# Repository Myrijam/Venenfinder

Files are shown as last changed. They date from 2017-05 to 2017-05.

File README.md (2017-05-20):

# Venenfinder
Assistive medical device to help localizing veins for intravenous access...

Medication that can’t be ingested through the gastrointestinal tract has to be injected intravenous - usually by a doctor but in chronic diseases it can also be carried out by yourself  ("home treatment", for example, venous puncture with medication 3 times per week).
Venous blood vessels used for medication are not always easy to recognize and if the needle is not secure in the vein, it must be punctured again at another point.  Here our project comes into play: Using NIR (near infrared) Illumination and real-time image processing, we can make the veins more visible!

We (my brother Elias, Lucie [a friend of mine] and me) submitted this project to Jugend Forscht. It will take part in the German Final in a week! Please keep your fingers crossed...
Our aim was to develop an assistive technology for venous puncture for diagnostic purposes (blood sampling) or for medical drug administration.
Easy reproduction and low costs are important criteria for development.

In addition to the research and review of specialist literature on methods of venous localization and optical characteristics of human skin, we carry out our own experiments. This Project contains the Python code needed for a mobile version that uses a smartphone or tablet as a display as well as the 3d-files needed to print it.
Please check the setup-file for a detailed description.

This Project is licensed under the Creative Commens license: CC BY NC SA.

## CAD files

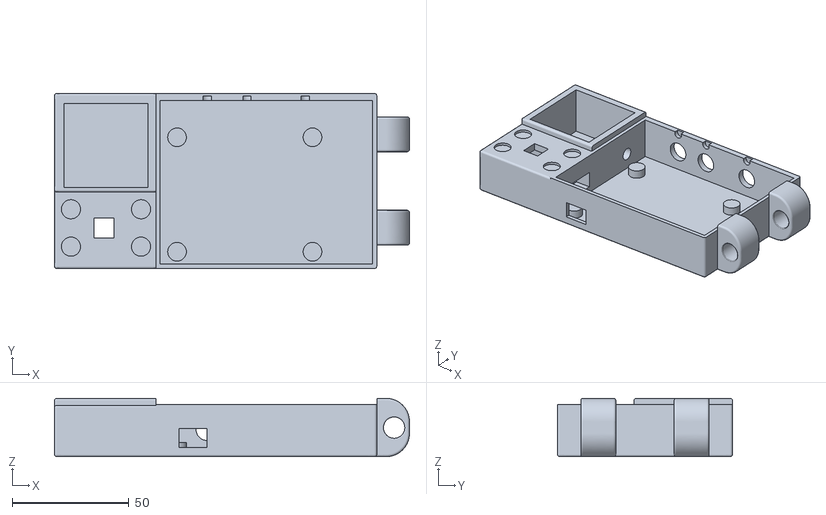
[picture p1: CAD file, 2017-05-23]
3d_files/Vene_main_case.stl
152.0 x 75.0 x 25.0

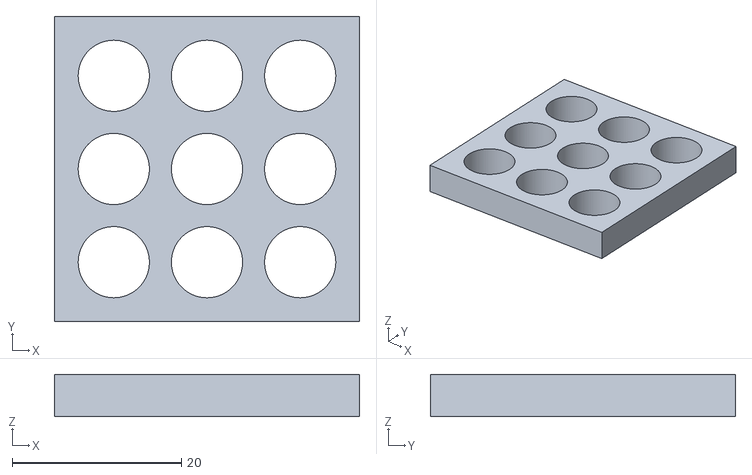
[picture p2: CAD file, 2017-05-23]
3d_files/IR-LED-reflector-Matrix_Venenfinder.stl
36.0 x 36.0 x 5.00

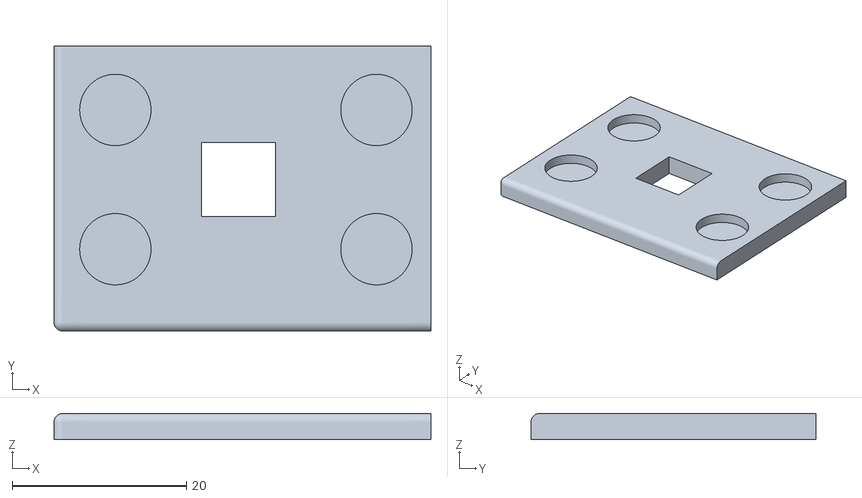
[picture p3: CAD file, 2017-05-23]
3d_files/IR-Filter_MagneticClip_Venenfinder.stl
43.3 x 32.8 x 3.00

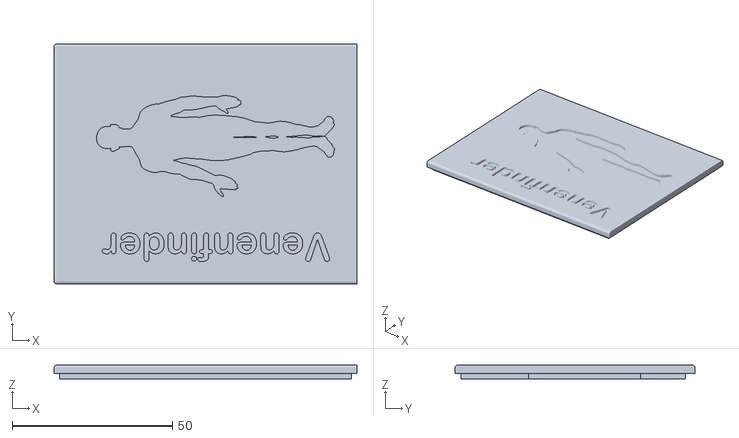
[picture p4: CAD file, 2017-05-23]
3d_files/Cover_Venenfinder.stl
94.5 x 75.0 x 4.40

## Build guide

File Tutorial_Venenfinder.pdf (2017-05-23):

Venenfinder – a DIY medical assistive device.
Elias Stoetzer (12), Lucie Ettlinger (16), Myrijam Stoetzer (16)

Venenfinder – a DIY medical assistive device.

This tutorial describes how to build the „Venenfinder“ (vein-finder) from scratch. It is a medical assistive device that was developed by us to make it easier for medical stuff as well as people with chronic illnesses to get vein access.

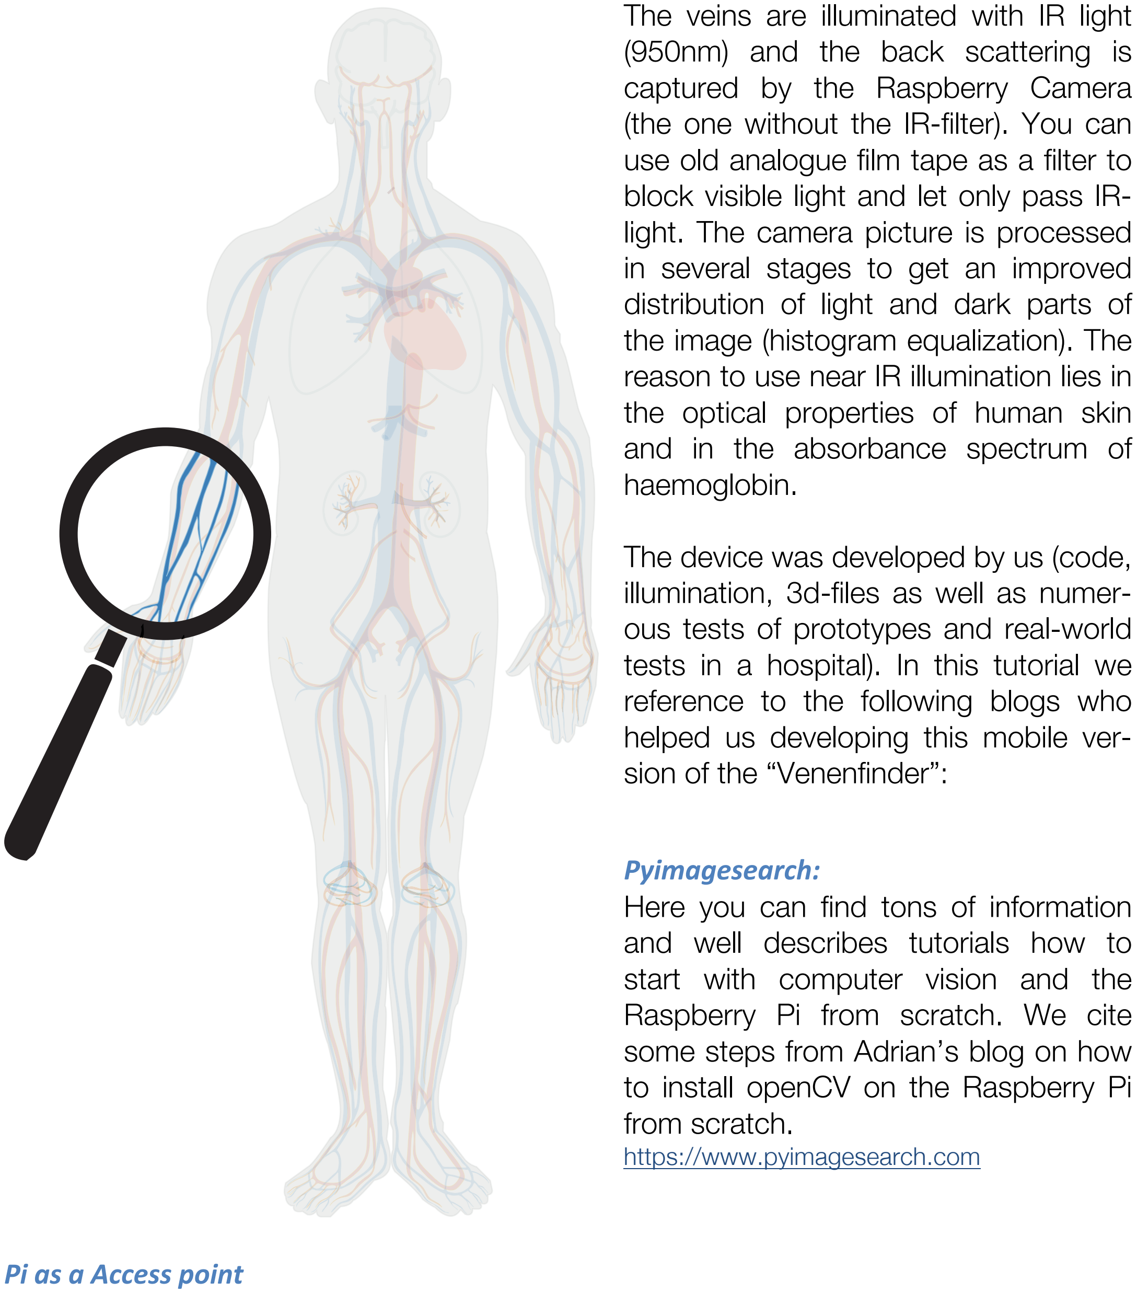
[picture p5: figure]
The veins are illuminated with IR light (950nm) and the back scattering is captured by the Raspberry Camera; light. The camera picture is processed in several stages to get an improved distribution of light and dark parts of the image (histogram equalization). The; the optical properties of human skin and in the absorbance spectrum of haemoglobin.; The device was developed by us (code,; ous tests of prototypes and real-world; reference to the following blogs who helped us developing this mobile ver- sion of the “Venenfinder”: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

(the one without the IR-filter). You can use old analogue film tape as a filter to block visible light and let only pass IR-

reason to use near IR illumination lies in

illumination, 3d-files as well as numer-

tests in a hospital). In this tutorial we

If you want to stream the calculated image to your smartphone, TV or tablet, you either need to integrate the Raspberry into your local Wifi network – or just start a new one. We don’t want the user to have to deal with editing wifi settings on a terminal session, so we just decided to turn the Pi into a Hotspot. Here we followed Phil Martin’s blog on how to use the Raspberry as a Wifi Accesspoint:
https://frillip.com/using-your-raspberry-pi-3-as-a-wifi-access-point-with-hostapd/

Rotary encoder:
Since you need a way to change the setting of the image enhancement, we decided to use rotary encoders. These are basically just 2 switches and they sequence they close and open tells you the direction the knob was turned.
We soldered 3 rotary encoders to a little board and created a Raspberry HAT on our own. For the code we used:
http://www.bobrathbone.com/raspberrypi/Raspberry%20Rotary%20Encoders.pdf

Streaming Server in Python:
We used some code from Igor Maculan – he programmed a Simple Python Motion Jpeg (mjpeg) Server using a webcam, and we changed it to Picam, added the encoder and display of parameters. Original Code:
https://gist.github.com/n3wtron/4624820

## Install / Compile Softwarecomponents

1. download Jessie (full) from Raspberri.org (Version 2017-04-10)
2. unzip file and write the image to an SD-Card (e.g. using Apple Pi-Baker or other tools; see e.g. https://www.raspberrypi.org/documentation/installation/installingimages/)
3. start the system with the new sd-card and configure it according to... http://www.pyimagesearch.com/2016/04/18/install-guide-raspberry-pi-3-raspbian-jessie-opencv-3/
4. Make sure network connections work (WiFi or LAN) – you need to download software packets

Steps to install the Software, OS, Network

Follow the steps in Adrian’s tutorial http://www.pyimagesearch.com/2015/10/26/howto-install-opencv-3-on-raspbian-jessie/

1. expand filesystem (automatic)
2. updates: (sudo apt-get update & sudo apt-get upgrade)
3. install the packages as described, but download opencv3.2 and additions for 3.2

Install packages:
developer tools:
sudo apt-get install build-essential git cmake pkg-config
image I/O packages
sudo apt-get install libjpeg-dev libtiff5-dev libjasper-dev libpng12-dev

video I/O packages:
sudo apt-get install libavcodec-dev libavformat-dev libswscale-dev libv4ldev
sudo apt-get install libxvidcore-dev libx264-dev
display images, gui etc:
sudo apt-get install libgtk2.0-dev
extra optimation for matrix operations:
sudo apt-get install libatlas-base-dev gfortran
Python 2.7 und 3 header files:
sudo apt-get install python2.7-dev python3-dev
Source-Files:
wget -O opencv.zip https://github.com/Itseez/opencv/archive/3.2.0.zip unzip opencv.zip

wget -O opencv_contrib.zip https://github.com/Itseez/opencv_contrib/archive/3.2.0.zip
unzip opencv_contrib.zip
python package manager
wget https://bootstrap.pypa.io/get-pip.py sudo python get-pip.py
install numpy (numerical python)
pip install numpy
compile opencv
cd ~/opencv-3.2.0/
mkdir build
cd build
cmake -D CMAKE_BUILD_TYPE=RELEASE \
-D CMAKE_INSTALL_PREFIX=/usr/local \
-D INSTALL_PYTHON_EXAMPLES=ON \
-D OPENCV_EXTRA_MODULES_PATH=~/opencv_contrib-3.2.0/modules \ -D BUILD_EXAMPLES=ON ..

make -j4
(This takes a good 45-60min).

Now openCV should be installed with all the necessary additions. Please test it by rebooting and starting Python 2:
sudo shutdown -r now
After reboot and login start Python interpreter either by choosing IDLE-Python 2 from program menu or by typing into terminal:
python

>>>import cv2
(should produce no errors)

Hardware, 3D-files etc.

For the hardware you simply need to print the stl-files according to your 3D-Printer’s software. The case is designed to fit the Raspberry Pi3 with the three encoders at-

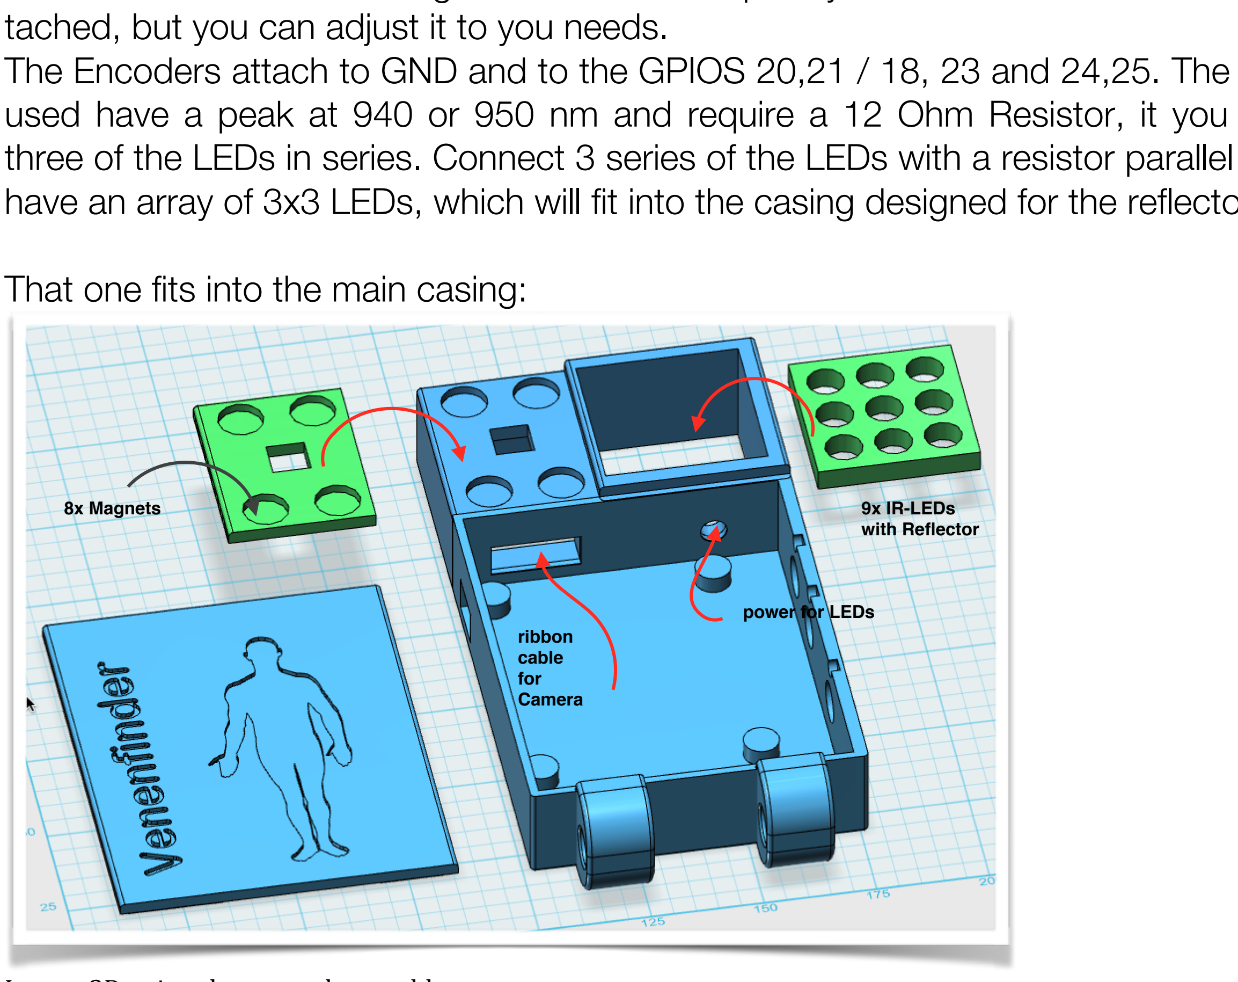
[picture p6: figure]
That one fits into the main casing:; 8x Magnets; 9x IR-LEDs; with Reflector; ribbon cable for Camera; power for LEDs

tached, but you can adjust it to you needs.
The Encoders attach to GND and to the GPIOS 20,21 / 18, 23 and 24,25. The IR-LEDs used have a peak at 940 or 950 nm and require a 12 Ohm Resistor, it you connect three of the LEDs in series. Connect 3 series of the LEDs with a resistor parallel and you have an array of 3x3 LEDs, which will fit into the casing designed for the reflectors.

Image: 3D-printed parts and assembly

Print the cover and the main casing with support; the adapter for the filter (analogue film tape) and IR reflector matrix won’t need support.

The circuit diagram for connecting LEDs and encoders:

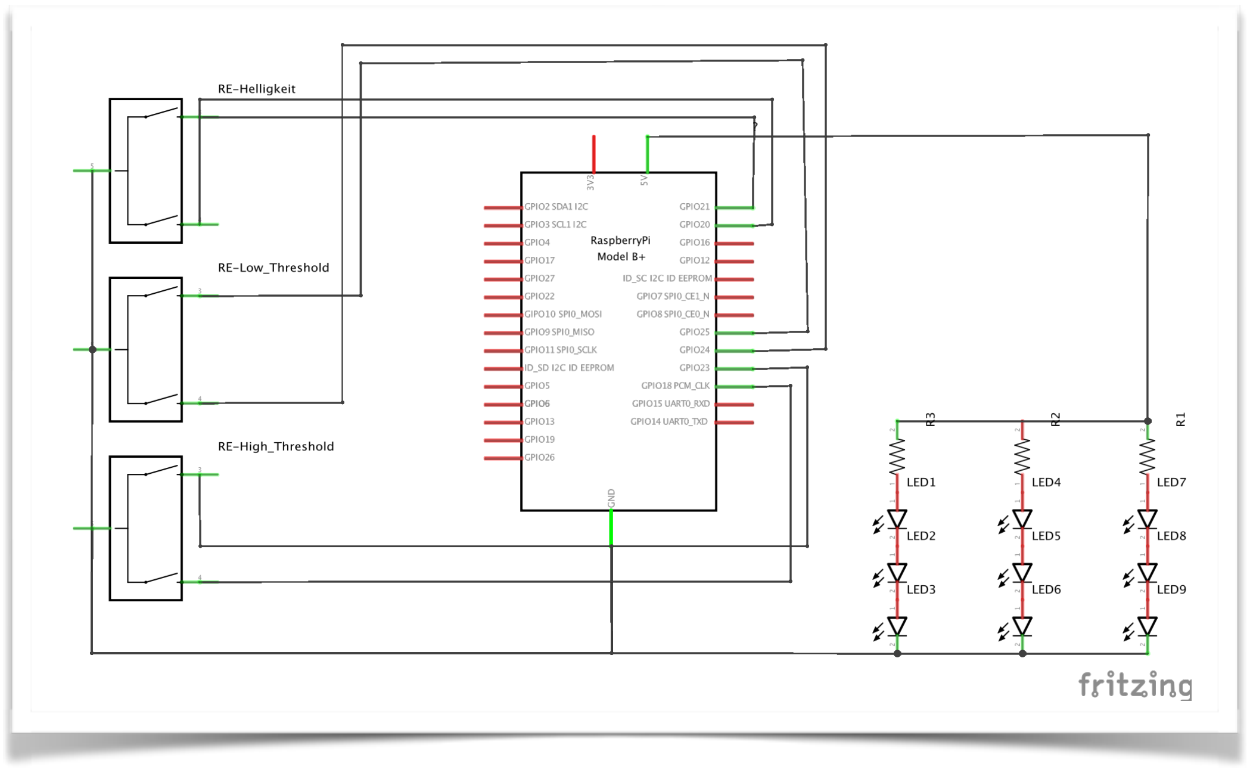
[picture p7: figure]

For our mobile version of the Venenfinder we used a piece of strip board, but if you want to build your own circuit board please keep in mind you may need to change the case to fit yours in…

Putting it all together: Wifi Access-Point, Autostart etc.

You can find the latest version of Venenfinder on Myrijam’s github page, including the code (Python script) and the 3d-files. All you need to do is to clone the git to your raspberry pi (or your regular computer to work with the 3d-files). https://github.com/Myrijam/Venenfinder
Server-Installation (Python)
Python already includes a simple http server you can use. It is just a little line of code to import the corresponding libraries into your python code (don’t run this in terminal):
from BaseHTTPServer import BaseHTTPRequestHandler,HTTPServer
from SocketServer import ThreadingMixIn

Wifi-Configuration (
These steps are mainly a short excerpt from Phil Martin’s blog:

Install hostapd (which will give you the ability to run an Accesspoint with building Wifi) and dnsmasq (combined DNS and DHCP Server):
sudo apt-get install dnsmasq hostapd

Edit the WLAN0-interface (build-in Wifi) preferences by using an editor on the commandline:
sudo nano /etc/dhcpcd.conf

add this line at the bottom, before any instructions starting with “interface” (if there are any)
denyinterfaces wlan0
Accesspoint needs a fixed (static) IP, so that the QR-Codes can work on the back of the device. Open this file and edit the section starting with WLAN0:
sudo nano /etc/network/interfaces
It should look like:
allow-hotplug wlan0
iface wlan0 inet static
address 192.168.42.1
netmask 255.255.255.0

Now you can restart the dhcp-service and reload the changed configuration:
sudo service dhcpcd restart
sudo ifdown wlan0; sudo ifup wlan0
Now the hostapd needs to be configured:

Create/edit the file by this command:
sudo nano /etc/hostapd/hostapd.conf
This is the content of hostapd.conf

# This is the name of the WiFi interface we configured above interface=wlan0

# Use the nl80211 driver with the brcmfmac driver driver=nl80211

# This is the name of the network ssid=Venenfinder

# Use the 2.4GHz band

hw_mode=g
# Use channel 6

channel=6
# Enable 802.11n

ieee80211n=1
# Enable WMM

wmm_enabled=1
# Enable 40MHz channels with 20ns guard interval ht_capab=[HT40][SHORT-GI-20][DSSS_CCK-40]

# Accept all MAC addresses

macaddr_acl=0
# Use WPA authentication

auth_algs=1
# Require clients to know the network name ignore_broadcast_ssid=0

# Use WPA2

wpa=2
# Use a pre-shared key

wpa_key_mgmt=WPA-PSK
# The network passphrase

wpa_passphrase=vene1181
# Use AES, instead of TKIP

rsn_pairwise=CCMP

Please pay attention to the statements in bold – these are SSID and PW of the device. It is not an elegant solution to hard-code any password in, but in the rush for the final we could not find an easier configuration –so please change them!

Now tell the hostapd where to look for the config file:
sudo nano /etc/default/hostapd

change the line from #DAEMON_CONF="" to DAEMON_CONF="/etc/hostapd/hostapd.conf"

Next step is to change the config of DNSMASQ. Phil Martin suggests to copy the preconfigured file and keep it that way before creating a new one:

sudo mv /etc/dnsmasq.conf /etc/dnsmasq.conf.orig

And then create a new config file:
sudo nano /etc/dnsmasq.conf
Paste the following content:
interface=wlan0 | # Use interface wlan0
listen-address=192.168.42.1 | # Address to listen on
bind-interfaces | # Bind to the interface
server=8.8.8.8 | # Forward DNS requests to Google DNS

domain-needed | # Don't forward short names
bogus-priv | # Never forward non-routed address spaces.
dhcp-range=192.168.42.10,192.168.42.150,12h # Clients IP range and time
Now it is time to set the rules for managing traffic on the interfaces:
sudo nano /etc/sysctl.conf

Search fort he line containing net.ipv4.ip_forward=1 and remove the # from the beginning of the line. Enable this rule by:
sudo sh -c "echo 1 > /proc/sys/net/ipv4/ip_forward"
The following commands define the traffic routing between Wifi and Ethernet; it is probably not necessary for this special use case:
sudo iptables -t nat -A POSTROUTING -o eth0 -j MASQUERADE
sudo | iptables | -A FORWARD | -i | eth0 | -o wlan0 | -m state | --state | RELAT-
ED,ESTABLISHED -j ACCEPT
sudo iptables -A FORWARD -i wlan0 -o eth0 -j ACCEPT

These rules need to run every time at bootup, so this saves the rules for later use:
sudo sh -c "iptables-save > /etc/iptables.ipv4.nat"

Now run the following command to enable restoring these rules at bootup:
sudo nano /etc/rc.local

Just before the line exit 0 enter the following command:
iptables-restore < /etc/iptables.ipv4.nat

Now you just need to restart the corresponding services:
sudo service hostapd start
sudo service dnsmasq start
Now the Raspberry 3 should work as an access point, providing a network with the specified SSID (“Venenfinder”) and the PSK (“vene1181”).
To make sure the device runs the Venenfinder-Python code at reboot, please refer to the following section.
Autostart
Use the following command to add autostart to the Python Code from Venenfinder :
sudo nano /etc/profile

And put a last line to the script:
python /home/pi/Venenfinder/Venenfinder.py
Rebooting the Raspberry will start the Venenfinder now :-)

## Connecting…

You can scan these QR-Codes to connect to Venenfinder, given you used the combination of SSID and PSK provided in this tutorial:

QR-Code for Wifi-Network

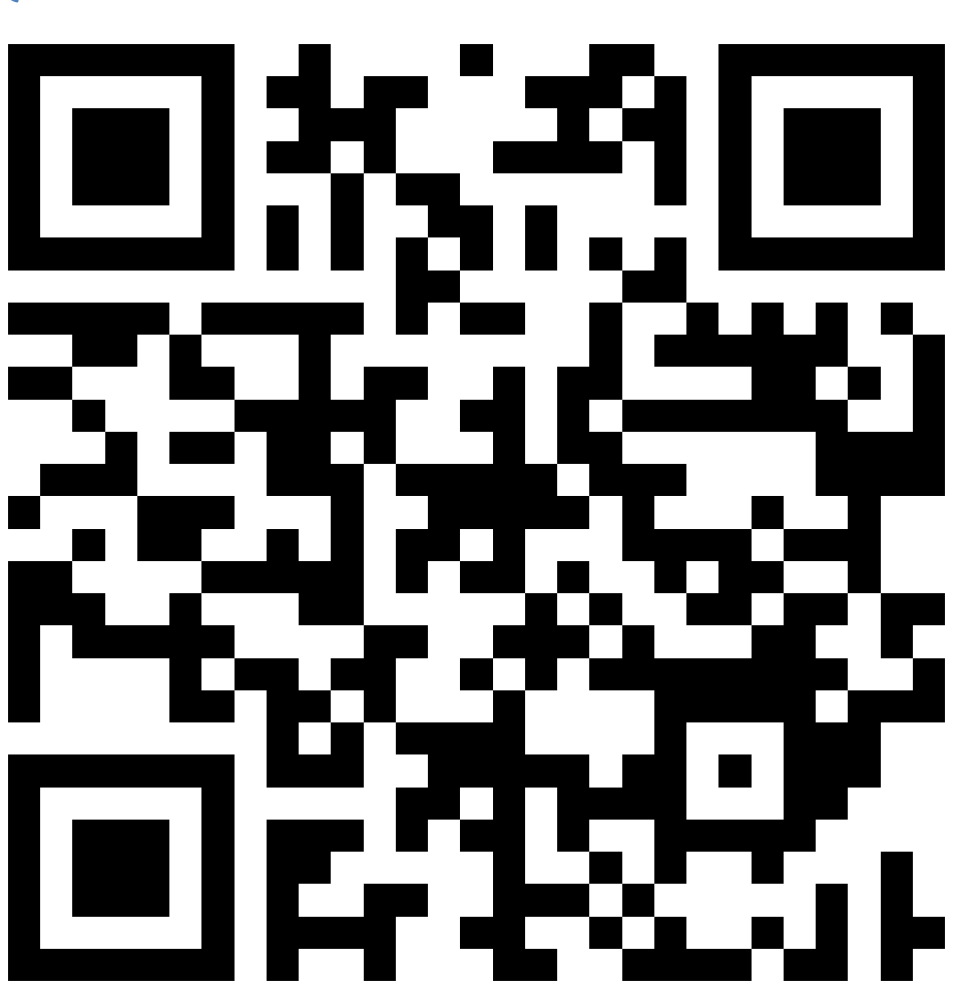
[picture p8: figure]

SSID: Venenfinder PSK: vene1181

QR-Code for Live-Streaming (Android, Computer):

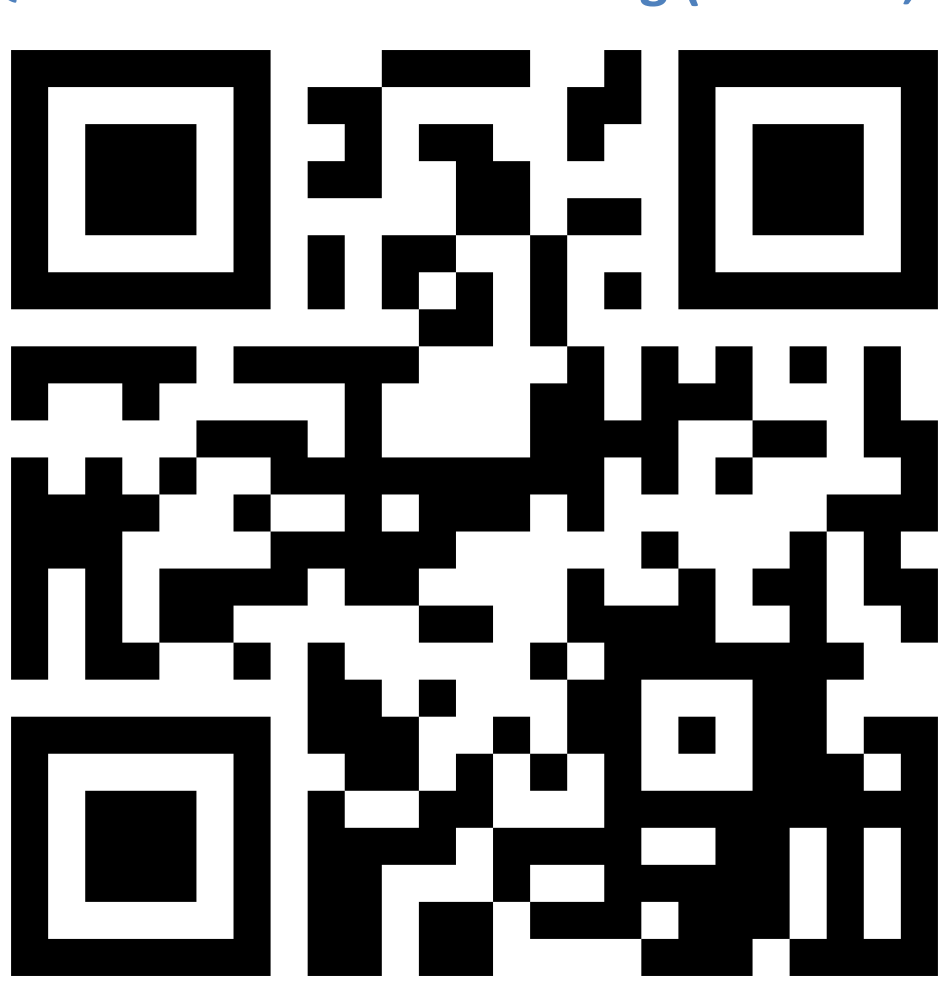
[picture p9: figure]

http://192.168.42.1:8080/cam.mjpg

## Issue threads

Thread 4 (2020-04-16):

Brasil - Help -  code before implementing the image server

Gurugoldberg, 2020-04-16:
Hello, how are you?

I have a difficulty with the hotspot, I think about using the LCD of the RPI itself or direct to TV
Do you have changes (code)  **before**  implementing the image server?

Thank you very much

my email is:
Andre Goldberg
<meuemaileandregoldberg@gmail.com>

e-Darwish, 2021-04-21:
Hello Andre,

I'm currently implementing this project with night vision camera and HDMI 7" LCD. I have just installed openCV from the [website ](https://pimylifeup.com/raspberry-pi-opencv/). I will clone the code to a folder on the RPi 4. Have you changed ant thing in the code to display the video on the LCD?

You can contact me on e_ahmeddarwish@hotmail.com or WhatsApp wa.me/96551105252

Thanks in advance

shayneoneill, 2021-07-06:
Just so you know folks, "please email me help with my program" isn't how Github issues work. Its useless for anyone searching for answers, and its not ACTUALLY an issue.

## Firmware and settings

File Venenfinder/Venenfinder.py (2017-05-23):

#!/usr/bin/python
# -*- coding: utf-8 -*-
# import the necessary packages / mobile Venenfinder
#
# We used some code as inspiration and as a starting point
# Streaming Server for MJPG from Igor Maculan 
# https://gist.github.com/n3wtron/4624820
# we changed it to Pycam, added encoders and display of parameters...
# Encoder examples and library:
# http://www.bobrathbone.com/raspberrypi/Raspberry%20Rotary%20Encoders.pdf

from __future__ import print_function

#from imutils.video import FPS
from picamera.array import PiRGBArray
from picamera import PiCamera
#import argparse
#import imutils
import time
import cv2
import numpy as np
from threading import Thread

from BaseHTTPServer import BaseHTTPRequestHandler,HTTPServer
from SocketServer import ThreadingMixIn

from rotary_class_2 import RotaryEncoder

count3 = 180
PIN_A3 = 23
PIN_B3 = 18

count1 = 40
PIN_A1 = 20
PIN_B1 = 21

count2 = 80
PIN_A2 = 24
PIN_B2 = 25

einstellung = False

#xres = 690
#yres = 300

# Größe der angezeigten Bilder
img_res_x = 800
img_res_y = 608


#x_roi = (img_res_x-xres)/2
#y_roi = (img_res_y-yres)/2


class CamHandler(BaseHTTPRequestHandler):
    def do_GET(self):
        global count1
        global count2
        global count3
        global x_roi
        global y_roi
        global xres
        global yres
        global camera
        if self.path.endswith('.mjpg'):
            self.send_response(200)
            self.send_header('Content-type','multipart/x-mixed-replace; boundary=--jpgboundary')
            self.end_headers()

            while True:
                   #Kamerabilder einlesen
                    img = vs.read()
                    #img = cv2.flip(img,1)
                    img_grey = cv2.cvtColor(img, cv2.COLOR_BGR2GRAY)

                    # Anpassung der Grauverteilung (adaptives Verfahren)
                    clahe = cv2.createCLAHE(clipLimit=2, tileGridSize=(8,8))
                    cl1 = clahe.apply(img_grey)

                    #cl1 = cv2.equalizeHist(img_grey)
                    clamp = np.uint8(np.interp(cl1, [count2, count3],[0,255]))

                    # neue adaptive Anpassung mit den Grenzwerten -> speichern in neuem Bild
                    equ = clahe.apply(clamp)
                    #equ = cv2.equalizeHist(clamp)
                    r,buf = cv2.imencode('.jpg', equ)

                    self.wfile.write("--jpgboundary")
                    self.send_header('Content-type','image/jpeg')
                    self.send_header('Content-length',str(len(buf)))
                    self.end_headers()
                    self.wfile.write(bytearray(buf))
                    #print (count2)
                    time.sleep(0.05)



        if self.path.endswith('.html'):
            self.send_response(200)
            self.send_header('Content-type','text/html')
            self.end_headers()
            self.wfile.write('<html><head></head><body>')
            self.wfile.write('<img src="http://127.0.0.1:8080/cam.mjpg"/>')
            self.wfile.write('</body></html>')
        return

class ThreadedHTTPServer(ThreadingMixIn, HTTPServer):
    """ nothing to see here """


class PiVideoStream:
    global count1
    #
    def __init__(self, resolution=(320, 240), framerate=32):
        # initialize the camera and stream
        self.camera = PiCamera()
        self.camera.resolution = resolution
        #if (einstellung != True):
        einstellung = True
        
        #print (count1)
        self.camera.iso = 400
        self.rawCapture = PiRGBArray(self.camera, size=resolution)
        self.stream = self.camera.capture_continuous(self.rawCapture, format="bgr", use_video_port=True)
        # initialize the frame and the variable used to indicate
        # if the thread should be stopped
        self.frame = None
        self.stopped = False

    def start(self):
        # start the thread to read frames from the video stream
        Thread(target=self.update, args=()).start()
        return self

    def update(self):
        
        # keep looping infinitely until the thread is stopped
        for f in self.stream:
                # grab the frame from the stream and clear the stream in
                # preparation for the next frame
                self.frame = f.array
                self.rawCapture.truncate(0)

                # if the thread indicator variable is set, stop the thread
                # and resource camera resources
                if self.stopped:
                        self.stream.close()
                        self.rawCapture.close()
                        self.camera.close()
                        return
    def read(self):
            # return the frame most recently read
            self.camera.brightness = count1
            self.camera.annotate_text_size = 20
            #self.camera.annotate_foreground = Color(0,0,1)
            self.camera.annotate_background = True
            self.camera.annotate_text = "H: "+ str(count1)+ "  S: "+ str(count2)+ "  W: "+ str(count3)
            #print(count1)
            return self.frame

    def stop(self):
            # indicate that the thread should be stopped
            self.stopped = True





##



def switch_event1(event):
        global count1
        if event == RotaryEncoder.CLOCKWISE:
                #print "Clockwise"
                count1 = count1+5
                if count1 > 90:
                        count1 = 90
                #print count1        
        elif event == RotaryEncoder.ANTICLOCKWISE:
                #print "Anticlockwise"
                count1 = count1-5
                if count1 < 10:
                        count1 = 10
                #print count1
        return

def switch_event2(event):
        global count2
        if event == RotaryEncoder.CLOCKWISE:
                #print "Clockwise"
                count2 = count2+5
                if count2 > 180:
                        count2 = 180
                #print count2        
        elif event == RotaryEncoder.ANTICLOCKWISE:
                #print "Anticlockwise"
                count2 = count2-5
                if count2 < 80:
                        count2 = 80
                #print count2
        return

def switch_event3(event):
        global count3
        if event == RotaryEncoder.CLOCKWISE:
                #print "Clockwise"
                count3 = count3+5
                if count3 > 220:
                        count3 = 220
                #print count3        
        elif event == RotaryEncoder.ANTICLOCKWISE:
                #print "Anticlockwise"
                count3 = count3-5
                if count3 < 150:
                        count3 = 150
                #print count3
        return



# Define the switch

hell = RotaryEncoder(PIN_A1,PIN_B1,switch_event1)
lower = RotaryEncoder(PIN_A2,PIN_B2,switch_event2)
higher = RotaryEncoder(PIN_A3,PIN_B3,switch_event3)
		

#
# initialize the camera and stream
camera = PiCamera()
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

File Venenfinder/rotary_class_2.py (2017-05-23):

#!/usr/bin/env python
#
# Raspberry Pi Rotary Encoder Class
# $Id: rotary_class.py,v 1.2 2014/01/14 07:30:07 bob Exp $
#
# Author : Bob Rathbone
# Site   : http://www.bobrathbone.com
#
# This class uses standard rotary encoder with push switch
#
#
#
# This class uses standard rotary encoder with push switch
#
#
import RPi.GPIO as GPIO
class RotaryEncoder:
    CLOCKWISE=1
    ANTICLOCKWISE=2
    BUTTONDOWN=3
    BUTTONUP=4
    rotary_a = 0
    rotary_b = 0
    rotary_c = 0
    last_state = 0
    direction = 0
  # Initialise rotary encoder object
    def __init__(self,pinA,pinB,callback):
      self.pinA = pinA
      self.pinB = pinB
      #self.button = button
      self.callback = callback
      GPIO.setmode(GPIO.BCM)
      # The following lines enable the internal pull-up resistors
      # on version 2 (latest) boards
      GPIO.setwarnings(False)
      GPIO.setup(self.pinA, GPIO.IN, pull_up_down=GPIO.PUD_UP)
      GPIO.setup(self.pinB, GPIO.IN, pull_up_down=GPIO.PUD_UP)
      #GPIO.setup(self.button, GPIO.IN, pull_up_down=GPIO.PUD_UP)
      # For version 1 (old) boards comment out the above four lines
      # and un-comment the following 3 lines
      #GPIO.setup(self.pinA, GPIO.IN)
      #GPIO.setup(self.pinB, GPIO.IN)
      #GPIO.setup(self.button, GPIO.IN)
      # Add event detection to the GPIO inputs
      GPIO.add_event_detect(self.pinA, GPIO.FALLING, callback=self.switch_event)
      GPIO.add_event_detect(self.pinB, GPIO.FALLING, callback=self.switch_event)
      #GPIO.add_event_detect(self.button, GPIO.BOTH, callback=self.button_event, bouncetime=200)
      return


# Call back routine called by switch events
    def switch_event(self,switch):
        if GPIO.input(self.pinA):
            self.rotary_a = 1
        else:
            self.rotary_a = 0
        if GPIO.input(self.pinB):
            self.rotary_b = 1
        else:
            self.rotary_b = 0

        self.rotary_c = self.rotary_a ^ self.rotary_b
        new_state = self.rotary_a * 4 + self.rotary_b * 2 + self.rotary_c * 1
        delta = (new_state - self.last_state) % 4
        self.last_state = new_state
        event = 0
        if delta == 1:
            if self.direction == self.CLOCKWISE:
                     # print "Clockwise"
                event = self.direction
            else:
                self.direction = self.CLOCKWISE
        elif delta == 3:
            if self.direction == self.ANTICLOCKWISE:
                     # print "Anticlockwise"
                event = self.direction
            else:
                self.direction = self.ANTICLOCKWISE
        if event > 0:
            self.callback(event)
        return
    # Push button event
    #def button_event(self,button):
       # if GPIO.input(button):
       #     event = self.BUTTONUP
      #  else:
       #     event = self.BUTTONDOWN
        #self.callback(event)
      #  return
    # Get a switch state
    def getSwitchState(self, switch):
       return  GPIO.input(switch)
    # End of RotaryEncoder class
